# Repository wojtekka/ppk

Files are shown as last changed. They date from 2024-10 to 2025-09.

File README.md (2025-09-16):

Palm™ Portable Keyboard USB adapter
===================================

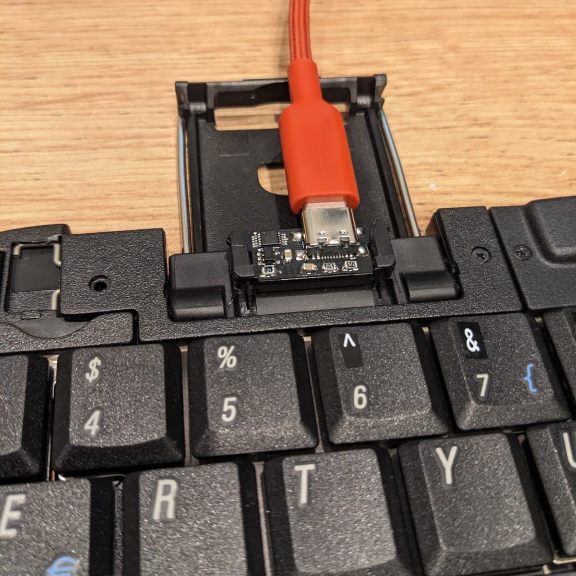
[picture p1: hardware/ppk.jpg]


Based on CH552 Macropad mini by Stefan Wagner (https://github.com/wagiminator/CH552-Macropad-mini). Headers from the original code:

    // ===================================================================================
    // Project:   MacroPad Mini for CH551, CH552 and CH554
    // Version:   v1.3
    // Year:      2023
    // Author:    Stefan Wagner
    // Github:    https://github.com/wagiminator
    // EasyEDA:   https://easyeda.com/wagiminator
    // License:   http://creativecommons.org/licenses/by-sa/3.0/
    // ===================================================================================

    # Project:   chprog - Programming Tool for CH55x Microcontrollers
    # Version:   v1.1
    # Year:      2022
    # Author:    Stefan Wagner
    # Github:    https://github.com/wagiminator
    # License:   MIT License

Based on Gist by Mightypork (https://gist.github.com/MightyPork/6da26e382a7ad91b5496ee55fdc73db2)

Key mapping compatible with https://github.com/pymo/ppk_bluetooth/

Hardware design released into public domain.

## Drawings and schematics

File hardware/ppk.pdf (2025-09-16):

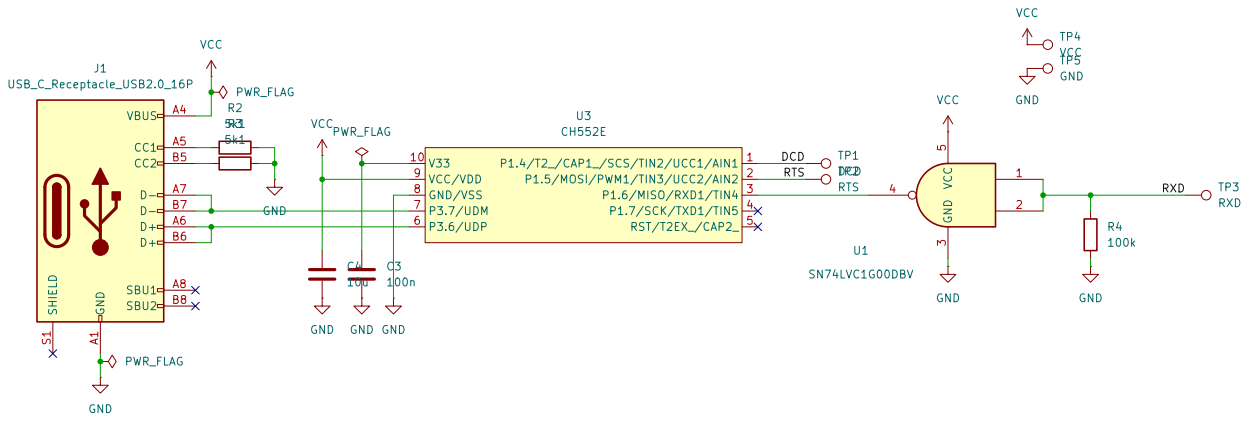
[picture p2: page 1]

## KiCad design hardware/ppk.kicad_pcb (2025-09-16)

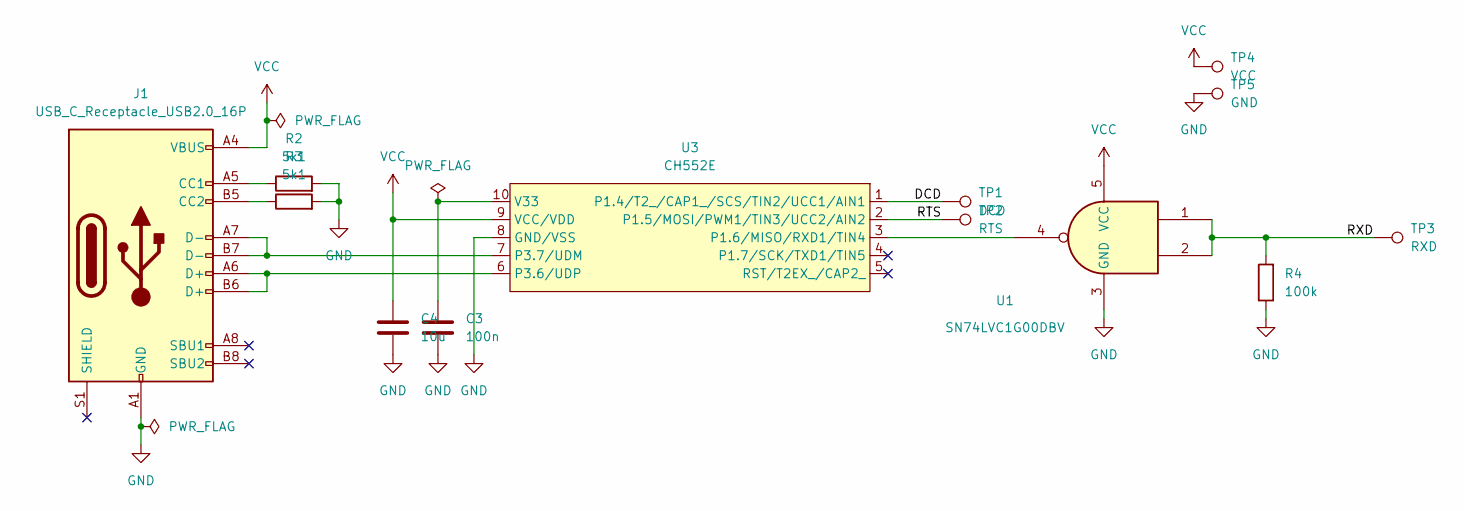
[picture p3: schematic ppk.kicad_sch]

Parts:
C3: 100n; C_0805_2012Metric
C4: 10u; C_0805_2012Metric
J1: USB_C_Receptacle_USB2.0_16P; USB_C_Receptacle_GCT_USB4110
R2, R3: 5k1; R_0805_2012Metric
R4: 100k; R_0805_2012Metric
TP1: DCD; TestPoint_Pad_1.5x1.5mm
TP2: RTS; TestPoint_Pad_1.5x1.5mm
TP3: RXD; TestPoint_Pad_1.5x1.5mm
TP4: VCC; TestPoint_Pad_1.5x1.5mm
TP5: GND; TestPoint_Pad_1.5x1.5mm
U1: SN74LVC1G00DBV; SOT-23-5
U3: CH552E; MSOP-10_3x3mm_P0.5mm

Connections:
/DCD: TP1.1, U3.1 (P1.4/T2_/CAP1_/SCS/TIN2/UCC1/AIN1)
/RTS: TP2.1, U3.2 (P1.5/MOSI/PWM1/TIN3/UCC2/AIN2)
/RXD: R4.2, TP3.1, U1.1, U1.2
GND: C3.2, C4.2, J1.A1 (GND), J1.A12 (GND), J1.B1 (GND), J1.B12 (GND), R2.2, R3.2, R4.1, TP5.1, U1.3 (GND), U3.8 (GND/VSS)
unnamed: J1.A5 (CC1), R2.1
unnamed: J1.B5 (CC2), R3.1
unnamed: U1.4, U3.3 (P1.6/MISO/RXD1/TIN4)
unnamed: J1.A6 (D+), J1.B6 (D+), U3.6 (P3.6/UDP)
unnamed: J1.A7 (D-), J1.B7 (D-), U3.7 (P3.7/UDM)
unnamed: C3.1, U3.10 (V33)
VCC: C4.1, J1.A4 (VBUS), J1.A9 (VBUS), J1.B4 (VBUS), J1.B9 (VBUS), TP4.1, U1.5 (VCC), U3.9 (VCC/VDD)

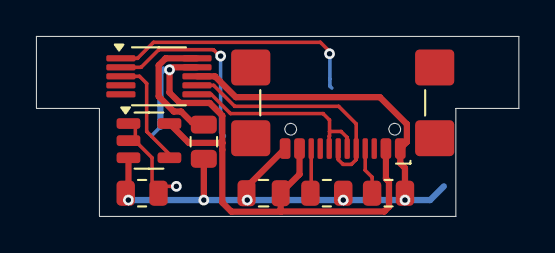
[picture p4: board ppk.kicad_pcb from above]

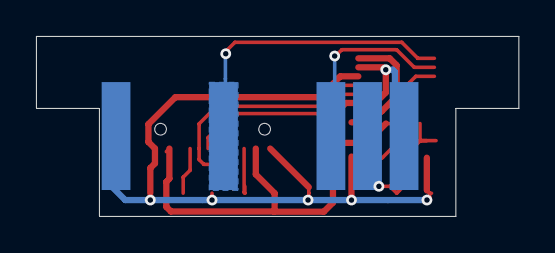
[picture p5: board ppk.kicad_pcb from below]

Board: 2 copper layers, 26.8 x 10.0 mm, 13 parts (5 on the bottom side), 11 nets.

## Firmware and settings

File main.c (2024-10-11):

#include "config.h"
#include "system.h"
#include "delay.h"
#include "usb_conkbd.h"
#include "usb_handler.h"
#include "gpio.h"
#include "mapping.h"
#include "uart.h"

void USB_ISR(void) __interrupt(INT_NO_USB)
{
    USB_interrupt();
}

void UART1_ISR(void) __interrupt(INT_NO_UART1)
{
    UART_interrupt();
}

#if 0
void print_char(char c)
{
    if (c == '\n')
    {
        print_char('\r');
    }

    UART_send(c);
}

void print_hex(char x)
{
    static const char hex[] = "0123456789abcdef";
    print_char(hex[((unsigned char)x) >> 4]);
    print_char(hex[((unsigned char)x) & 15]);
}

void print(const char *str)
{
    while (*str != 0)
    {
        print_char(*(str++));
    }
}
#endif

void main(void)
{
    /* RTS low */
    PIN_output(P15);
    PIN_low(P15);

    // Setup
    UART_init();
    CLK_config();
    DLY_ms(10); // wait for clock to settle

    // Wait for DCD
    PIN_input(P14);
    while (PIN_read(P14) != 1);

    // Set RTS high
    PIN_high(P15);

    // Init USB keyboard
    KBD_init();
    WDT_start();

    while(1)
    {
        WDT_reset();

        int tmp = UART_recv();
        if (tmp != -1)
        {
            MAP_handle(tmp);
        }
    }
}

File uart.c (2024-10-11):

#include "uart.h"

#include "system.h"

static __idata volatile uint8_t uart1_buf[16];
static __idata volatile uint8_t uart1_read = 0;
static __idata volatile uint8_t uart1_write = 0;

void UART_interrupt(void)
{
    if (U1RI)
    {
        U1RI = 0;

        uint8_t x = SBUF1;

        if (uart1_write - uart1_read == 16)
            return;

        uart1_buf[(uart1_write++) & 15] = x;
    }
}

void UART_init(void)
{
    U1REN = 1;
    SBAUD1 = 204;
    IE_UART1 = 1;
}

int UART_recv(void)
{
    int result = -1;

    EA = 0;
    if (uart1_read != uart1_write)
    {
        result = uart1_buf[(uart1_read++) & 15];
    }
    EA = 1;

    return result;
}

void UART_send(uint8_t x)
{
    SBUF1 = x;
    while (!U1TI);
    U1TI = 0;
}

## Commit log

2024-11-14 Use assigned USB pid/vid
2025-09-16 Hardware design in KiCad
    [ppk.kicad_pcb, ppk.kicad_sch]
